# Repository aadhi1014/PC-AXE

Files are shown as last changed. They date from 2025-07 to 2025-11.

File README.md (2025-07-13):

# PC-AXE: PCIe-Based Bitcoin Miner (12x BM1370, 14.4TH/s @ 200W)



**PC-AXE** is a compact, PCIe x4-based, open-hardware Bitcoin miner designed to plug directly into desktop computers. Inspired by [Bitaxe](https://github.com/skot/bitaxe), Bitcrane, and professional mining cards, PC-AXE uses twelve BM1370 ASIC chips and a 6-phase high-efficiency buck converter to deliver up to **14.4TH/s** of hashrate at just **200W** power draw.

**Note:** PC-AXE is a **work in progress**. Hardware files are being finalized, and firmware development is ongoing. Community contributions and testing feedback are welcome.

---

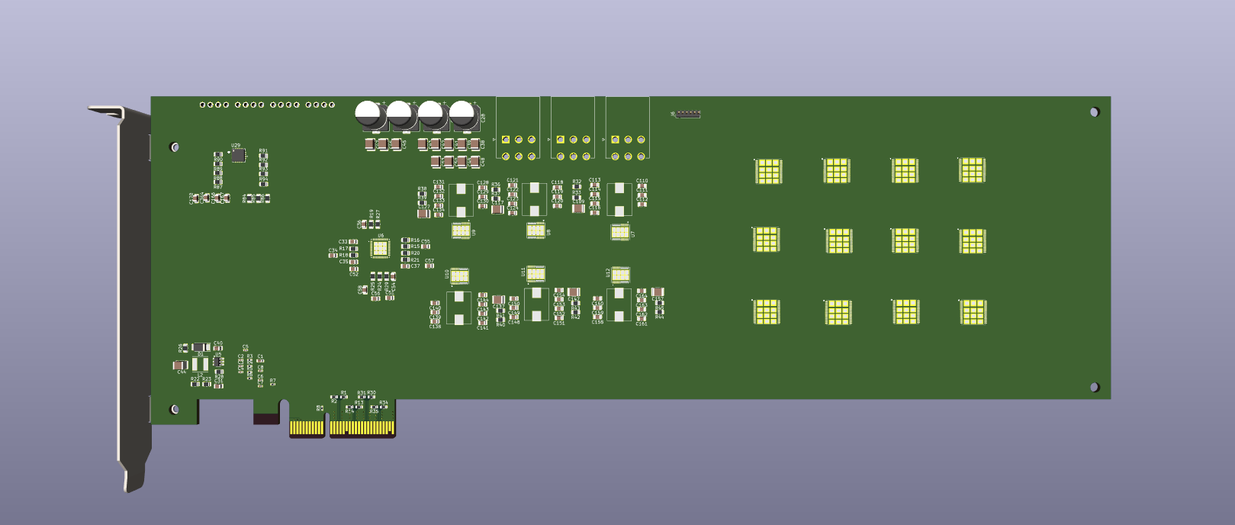
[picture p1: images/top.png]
PC-AXE Top View
  
*Top side of the PC-AXE board*

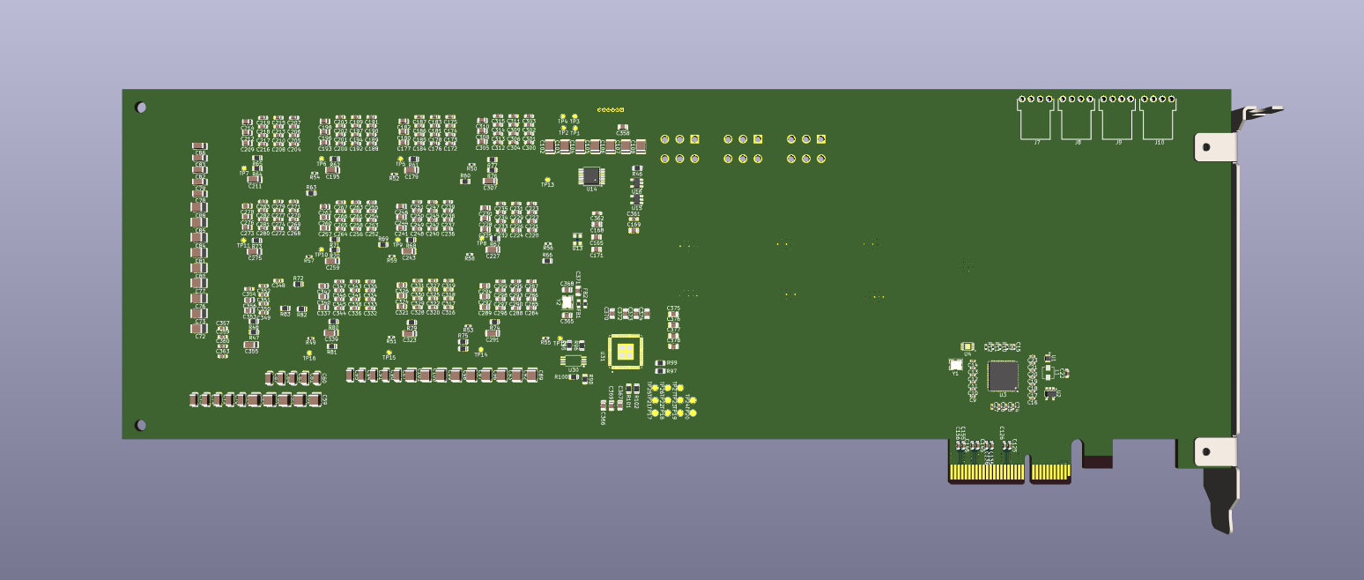
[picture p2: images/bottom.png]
PC-AXE Bottom View
  
*Bottom side of the PC-AXE board*

---

## Features

- **Standard PCIe x4 Form Factor**
  - Easily integrates into modern desktop systems
  - Powered via PCIe slot with external power input

- **12 × BM1370 ASIC Chips**
  - Same chips used in Antminer S21
  - Estimated hashrate of ~1.2TH/s per chip

- **6-Phase 180A Buck Converter**
  - High-efficiency power delivery at 1.1V
  - Total power consumption approximately 200W

- **Fully Open-Source Design**
  - Includes KiCad schematics, layout, and source files
  - Planned firmware compatibility with Bitaxe ecosystem

- **UART Debug Interface**
  - Communicates via USB-to-UART bridge (e.g. FT4232H)
  - Supports daisy-chained UART control for ASICs

- **Design Inspiration**
  - Derived from Bitaxe (compact solo miner)
  - Influenced by Bitcrane

---

## Getting Started

### Build Instructions

1. Open the project in KiCad 7 or newer
2. Review the schematic and PCB layout
3. Export Gerber files and order the PCB from your preferred manufacturer
4. Assemble the board using the BOM (to be published)
5. Flash control firmware (currently in development)

### UART Connection

Connect an FTDI FT4232H or equivalent USB-to-UART adapter to the debug header. A single UART channel can control all 12 ASICs.

---

## Important License Notice  
This project was relicensed under the **TAPR Open Hardware License – Non-Commercial (OHL-NC)** on **July 11, 2025**.  
All clones and forks made **after this date** are subject to **non-commercial use only**.  

**Commercial use, manufacturing, or distribution of this work is strictly prohibited without explicit written permission from the copyright holder.**  

If you cloned this repository *before July 11, 2025*, please contact the author for updated licensing terms.

---

## License

This hardware design is licensed under the TAPR Open Hardware License – Non-Commercial (OHL-NC).  
You are free to use, modify, and distribute for **non-commercial purposes**.  

**Commercial use requires explicit written permission from the copyright holder.**  
See the [LICENSE](LICENSE) file for details.

---

## Acknowledgments

This project draws inspiration and technical insight from several open-source mining hardware efforts:

- [Bitaxe](https://github.com/skot/bitaxe) – foundational open hardware Bitcoin miner  
- [NerdAxe](https://github.com/BitMaker-hub/NerdAxe) – compact ESP32-based BM1370 miner 
- [NerdOCTAXE-Gamma](https://github.com/5toliv/NerdOCTAXE-Gamma) – 8‑ASIC miner derived from NerdQaxe 
- [NerdEKO‑Gamma](https://github.com/phil31/NerdEKO-Gamma) – ESP32-based miner reference design   
- [Bitcrane](https://bitcointalk.org/index.php?topic=951507.0) – USB antminer control board  design

We thank these creators for their contributions to the open-source mining community.
---

## Contact / Collaboration

If you are a developer, hardware enthusiast, or miner interested in contributing to this open hardware project, feel free to open issues or pull requests. Community collaboration is welcome.

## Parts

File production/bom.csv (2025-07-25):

Designator | Footprint | Quantity | Value | LCSC Part #
C1 | 0603 | 1 | 10uF
C10, C11, C12, C13, C14, C16, C17, C18, C19, C23, C24, C27, C3, C4, C5, C6, C7, C8, C9 | 0402 | 19 | 100nF
C100, C101, C102, C103, C104, C105, C106, C107, C108, C59, C62, C65, C66, C69, C72, C73, C76, C77, C80, C81, C84, C85, C88, C89, C92, C93, C96, C97, C98, C99 | 1210 | 30 | 330µF/4V
C109, C117, C127, C137, C147, C157, C38, C39, C41, C42, C43, C44, C45, C46, C47, C48, C49, C50, C53 | 1210 | 19 | 22µ/25V
C110, C118, C128, C138, C148, C158, C169, C171, C180, C196, C212, C228, C244, C260, C276, C292, C308, C324, C340, C356, C52, C54 | 0805 | 22 | 1µF/25V
C111, C116, C119, C124, C129, C134, C139, C144, C149, C154, C159, C164, C36, C37, C58 | 0805 | 15 | 1nF
C112, C113, C115, C120, C121, C123, C130, C131, C133, C140, C141, C143, C150, C151, C153, C160, C161, C163, C165, C166, C167, C168, C170, C182, C198, C214, C230, C246, C262, C278, C294, C310, C326, C342, C358 | 0805 | 35 | 100nF
C114, C122, C132, C142, C152, C162 | 0805 | 6 | 2.2µF/16V
C125, C126, C135, C136, C145, C146, C155, C156 | 0603 | 8 | 100n
C15, C2 | 0402 | 2 | 10uF
C172, C173, C174, C175, C176, C178, C181, C183, C184, C185, C186, C187, C188, C189, C190, C191, C192, C194, C197, C199, C200, C201, C202, C203, C204, C205, C206, C207, C208, C210, C213, C215, C216, C217, C218, C219, C220, C221, C222, C223, C224, C226, C229, C231, C232, C233, C234, C235, C236, C237, C238, C239, C240, C242, C245, C247, C248, C249, C250, C251, C252, C253, C254, C255, C256, C258, C261, C263, C264, C265, C266, C267, C268, C269, C270, C271, C272, C274, C277, C279, C280, C281, C282, C283, C284, C285, C286, C287, C288, C290, C293, C295, C296, C297, C298, C299, C300, C301, C302, C303, C304, C306, C309, C311, C312, C313, C314, C315, C316, C317, C318, C319, C320, C322, C325, C327, C328, C329, C330, C331, C332, C333, C334, C335, C336, C338, C341, C343, C344, C345, C346, C347, C348, C349, C350, C351, C352, C354, C357, C359, C360, C361, C362, C363 | 0603 | 144 | 1µF/6.3V
C177, C193, C209, C225, C241, C257, C273, C289, C305, C31, C321, C337, C353 | 0805 | 13 | 10µF/25V
C179, C195, C211, C227, C243, C259, C275, C291, C307, C323, C339, C355, C60, C61, C63, C64, C67, C68, C70, C71, C74, C75, C78, C79, C82, C83, C86, C87, C90, C91, C94, C95 | 1206 | 32 | 100µ/6.3V
C20 | 0402 | 1 | 10pF
C21 | 0402 | 1 | 1uF
C22 | 0603 | 1 | 22uF
C25, C26 | 0402 | 2 | 18pF
C28, C29, C30, C32 | CP_Elec_8x10 | 4 | 470µ/25V
C33, C35 | 0805 | 2 | 22pF
C34 | 0805 | 1 | 100pF
C364, C369, C371, C372, C373, C374, C375, C376, C377, C378 | 0805 | 10 | 0.1uF | C28233
C365, C368 | 0805 | 2 | 27pf | C107113
C366, C367 | 0805 | 2 | 4.7uF | C1746
C370 | 0805 | 1 | 3.3uF | C159781
C40 | 0805 | 1 | 10nF
C51 | 0805 | 1 | 4.7µF/16V
C55 | 0805 | 1 | 330nF
C56 | 0805 | 1 | 12pF
C57 | 0805 | 1 | 2.2nF
D1 | D_SOD-128 | 1 | PMEG4030EP,115
FB1, FB2 | 0603 | 2 | FerriteBead_Small | C19330
J1 | PCIexpress_bracket_full | 1 | PCIexpress_bracket
J10, J7, J8, J9 | CONN-TH_4P-P2.54_HCTL_HC-2510-4AW | 4 | 61900411021 | C2982043
J2 | PCIexpress_x4 | 1 | PCIexpress_x4
J3, J4, J5 | MOLEX_353180620 | 3 | 353180620
L1 | L_Vishay_IHLP-1212 | 1 | 1uH
L2 | L_Taiyo-Yuden_NR-50xx | 1 | 4.7µH
L3, L4, L5, L6, L7, L8 | IFLR-4031GC-01-8x10 | 6 | 220nH
R1, R13, R14, R2, R30, R31, R34, R35 | 0603 | 8 | 49.9
R10 | 0402 | 1 | 6.04K
R100, R91, R92, R93, R94, R95, R98 | 0805 | 7 | 10k | C17414
R101 | 0805 | 1 | 12k | C17444
R102 | 0805 | 1 | 1k | C17513
R11 | 0402 | 1 | 15K
R12, R5, R6, R8 | 0402 | 4 | 10K
R15, R23 | 0805 | 2 | 16.5K
R16 | 0805 | 1 | 24.3K
R17, R18 | 0805 | 2 | 51 0.5%
R19 | 0805 | 1 | 121K
R20, R21, R46, R47, R48 | 0805 | 5 | 10K
R22 | 0805 | 1 | 86.6K
R24 | 0805 | 1 | 2.55K
R25 | 0805 | 1 | 8.06K
R26 | 0805 | 1 | 49.9K
R27 | 0805 | 1 | 100K
R28, R29 | 0805 | 2 | 2.2R
R3 | 0402 | 1 | 75K
R32, R33, R36, R37, R38, R39, R40, R41, R42, R43, R44, R45 | 0805 | 12 | 1R
R4 | 0402 | 1 | 100K
R49, R50, R51, R52, R53, R54, R55, R56, R57, R58, R59 | 0402 | 11 | 33R
R60, R62, R64, R66, R68, R70, R72, R74, R76, R78, R80, R82 | 0805 | 12 | 1K
R61, R63, R65, R67, R69, R71, R73, R75, R77, R79, R81, R83 | 0805 | 12 | 2K
R7 | 0402 | 1 | DNP
R84, R97, R99 | 0805 | 3 | 4.7k | C17673
R85 | 0805 | 1 | 33k | C17633
R86 | 0805 | 1 | 22k | C17560
R87, R88, R89, R90 | 0805 | 4 | 36k | C114527
R9 | 0402 | 1 | 4.7K
R96 | 0805 | 1 | 2.2k | C17520
TP1, TP10, TP11, TP12, TP13, TP14, TP15, TP16, TP2, TP3, TP4, TP5, TP6, TP7, TP8, TP9 | TestPoint_Pad_D1.0mm | 16 | TestPoint
U1 | SOT-563 | 1 | TLV62568ADRLR
U10, U11, U12, U7, U8, U9 | IC_CSD95490Q5MC | 6 | CSD95472Q5MC
U13 | Oscillator_SMD_EuroQuartz_XO32-4Pin_3.2x2.5mm | 1 | 25MHz
U14 | TSSOP-14-1EP_4.4x5mm_P0.65mm | 1 | TXU0304PW
U15 | SOT-23-5 | 1 | MCP1824T-0802E
U16 | SOT-23-5 | 1 | MCP1824T-1202E
U17, U18, U19, U20, U21, U22, U23, U24, U25, U26, U27, U28 | BM1370 | 12 | BM1370_mode1
U2 | SOT-23-5 | 1 | AP2204K-1.8
U29 | QFN16_4x4MC_MCH | 1 | EMC2305
U3 | QFN-68-1EP_8x8mm_P0.4mm_EP5.2x5.2mm | 1 | VL805
U30 | TSSOP-8_L4.4-W3.0-P0.65-LS6.4-BL | 1 | M93C46-WDW6TP | C616741
U31 | QFN50P900X900X105-65N | 1 | FT4232HQ | C2651882
U4 | DFN-8-1EP_3x2mm_P0.5mm_EP1.36x1.46mm | 1 | W25Q32JVZP
U5 | SOT-23-6 | 1 | AP3211
U6 | IC_TPS53667RTAR | 1 | TPS53667RTAR
Y1 | Crystal_SMD_3225-4Pin_3.2x2.5mm | 1 | 25Mhz
Y2 | Crystal_SMD_3225-4Pin_3.2x2.5mm | 1 | 12MHz | C251626

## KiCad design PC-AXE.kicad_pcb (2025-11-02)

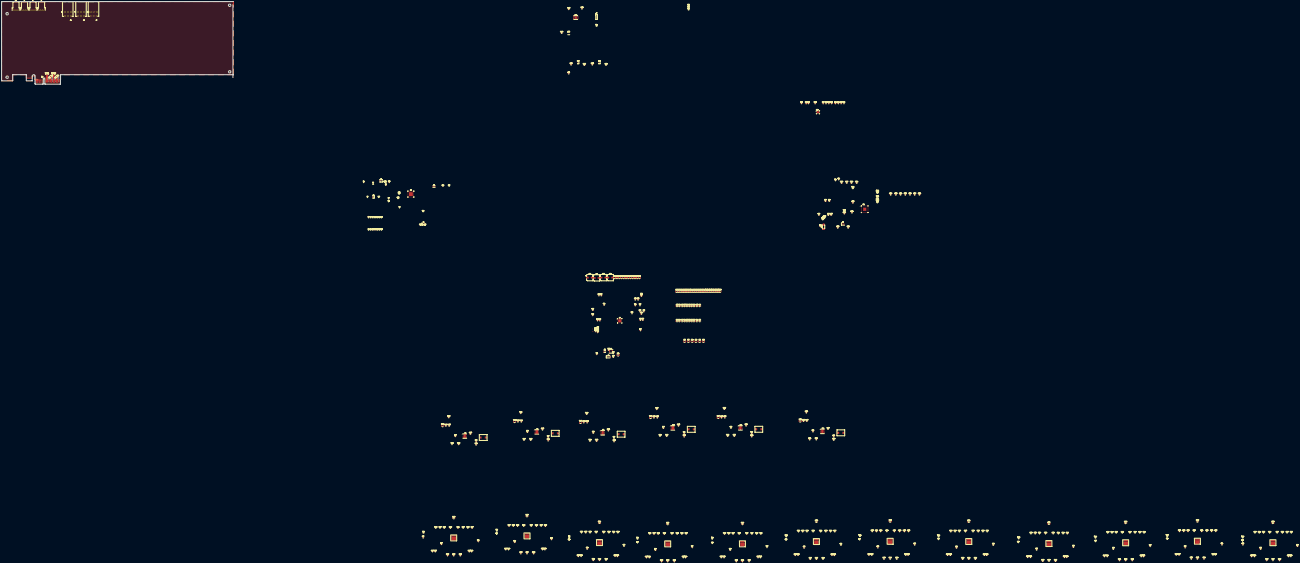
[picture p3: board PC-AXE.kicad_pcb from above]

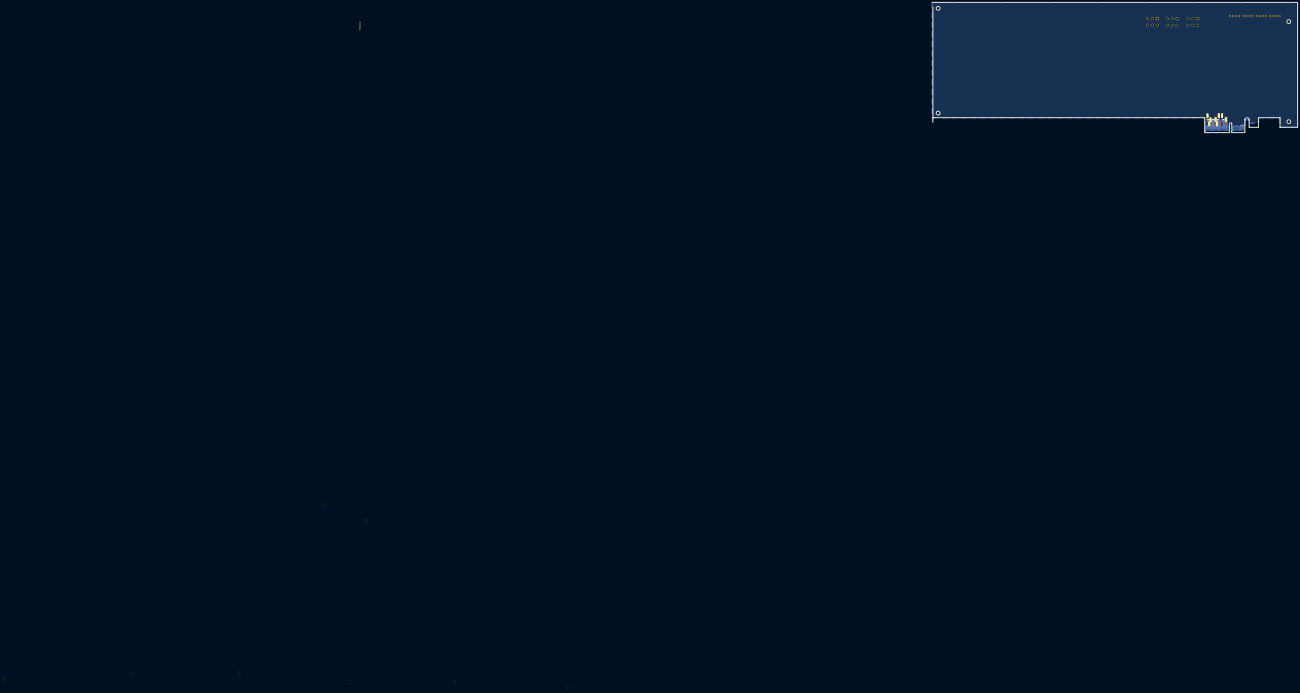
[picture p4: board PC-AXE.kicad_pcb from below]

Board: 6 copper layers, 312.0 x 111.2 mm, 563 parts (8 on the bottom side), 298 nets.

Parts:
C1: 10uF; C_0603_1608Metric
C2, C15: 10uF; C_0402_1005Metric
C3, C4, C5, C6, C7, C8, C9, C10, C11, C12, C13, C14, C16, C17, C18, C19, C23, C24, C27: 100nF; C_0402_1005Metric
C20: 10pF; C_0402_1005Metric
C21: 1uF; C_0402_1005Metric
C22: 22uF; C_0603_1608Metric
C25, C26: 18pF; C_0402_1005Metric
C28, C29, C30, C35: 470µ/25V; CP_Elec_8x10
C31, C177, C193, C209, C225, C241, C257, C273, C289, C305, C321, C337, C353: 10µF/25V; C_0805_2012Metric
C32, C34: 22pF; C_0805_2012Metric
C33: 100pF; C_0805_2012Metric
C36, C37, C58, C111, C116, C119, C124, C129, C134, C139, C144, C149, C154, C159, C164: 1nF; C_0805_2012Metric
C38, C39, C41, C42, C43, C44, C45, C46, C47, C48, C49, C52, C54, C109, C117, C127, C137, C147, C157: 22µ/25V; C_1210_3225Metric
C40: 10nF; C_0805_2012Metric
C50: 4.7µF/16V; C_0805_2012Metric
C51, C53, C110, C118, C128, C138, C148, C158, C169, C171, C180, C196, C212, C228, C244, C260, C276, C292, C308, C324, C340, C356: 1µF/25V; C_0805_2012Metric
C55: 330nF; C_0805_2012Metric
C56: 12pF; C_0805_2012Metric
C57: 2.2nF; C_0805_2012Metric
C59, C62, C65, C66, C69, C72, C73, C76, C77, C80, C81, C84, C85, C88, C89, C92, C93, C96, C97, C98, C99, C100, C101, C102, C103, C104, C105, C106, C107, C108: 330µF/4V; C_1210_3225Metric
C60, C61, C63, C64, C67, C68, C70, C71, C74, C75, C78, C79, C82, C83, C86, C87, C90, C91, C94, C95, C179, C195, C211, C227, C243, C259, C275, C291, C307, C323, C339, C355: 100µ/6.3V; C_1206_3216Metric
C112, C113, C115, C120, C121, C123, C130, C131, C133, C140, C141, C143, C150, C151, C153, C160, C161, C163, C165, C166, C167, C168, C170, C182, C198, C214, C230, C246, C262, C278, C294, C310, C326, C342, C358: 100nF; C_0805_2012Metric
C114, C122, C132, C142, C152, C162: 2.2µF/16V; C_0805_2012Metric
C125, C126, C135, C136, C145, C146, C155, C156: 100n; C_0603_1608Metric
C172, C173, C174, C175, C176, C178, C181, C183, C184, C185, C186, C187, C188, C189, C190, C191, C192, C194, C197, C199, C200, C201, C202, C203, C204, C205, C206, C207, C208, C210, C213, C215, C216, C217, C218, C219, C220, C221, C222, C223, C224, C226, C229, C231, C232, C233, C234, C235, C236, C237, C238, C239, C240, C242, C245, C247, C248, C249, C250, C251, C252, C253, C254, C255, C256, C258, C261, C263, C264, C265, C266, C267, C268, C269, C270, C271, C272, C274, C277, C279, C280, C281, C282, C283, C284, C285, C286, C287, C288, C290, C293, C295, C296, C297, C298, C299, C300, C301, C302, C303, C304, C306, C309, C311, C312, C313, C314, C315, C316, C317, C318, C319, C320, C322, C325, C327, C328, C329, C330, C331, C332, C333, C334, C335, C336, C338, C341, C343, C344, C345, C346, C347, C348, C349, C350, C351, C352, C354, C357, C359, C360, C361, C362, C363: 1µF/6.3V; C_0603_1608Metric_Pad1.08x0.95mm_HandSolder
C364, C369, C371, C372, C373, C374, C375, C376, C377, C378: 0.1uF; C_0805_2012Metric
C365, C368: 27pf; C_0805_2012Metric
C366, C367: 4.7uF; C_0805_2012Metric
C370: 3.3uF; C_0805_2012Metric
D1: PMEG4030EP,115; D_SOD-128
FB1, FB2: FerriteBead_Small; R_0603_1608Metric
J1: PCIexpress_bracket; PCIexpress_bracket_full
J2: PCIexpress_x4
J3, J4, J5: 353180620; MOLEX_353180620
J6: Conn_01x06; PinHeader_1x06_P1.27mm_Vertical
J7, J8, J9, J10: 61900411021; CONN-TH_4P-P2.54_HCTL_HC-2510-4AW
L1: 1uH; L_Vishay_IHLP-1212
L2: 4.7µH; L_Taiyo-Yuden_NR-50xx
L3, L4, L5, L6, L7, L8: 220nH; IFLR-4031GC-01-8x10
NT1, NT2: NetTie_2; NetTie-2_SMD_Pad0.5mm
R1, R2, R13, R14, R30, R31, R34, R35: 49.9; R_0603_1608Metric
R3: 75K; R_0402_1005Metric
R4: 100K; R_0402_1005Metric
R5, R6, R8, R12: 10K; R_0402_1005Metric
R7: DNP; R_0402_1005Metric
R9: 4.7K; R_0402_1005Metric
R10: 6.04K; R_0402_1005Metric
R11: 15K; R_0402_1005Metric
R15, R23: 16.5K; R_0805_2012Metric
R16: 24.3K; R_0805_2012Metric
R17, R18: 51 0.5%; R_0805_2012Metric
R19: 121K; R_0805_2012Metric
R20, R21, R46, R47, R48: 10K; R_0805_2012Metric
R22: 86.6K; R_0805_2012Metric
R24: 2.55K; R_0805_2012Metric
R25: 8.06K; R_0805_2012Metric
R26: 33.2K; R_0805_2012Metric
R27: 100K; R_0805_2012Metric
R28, R29: 2.2R; R_0805_2012Metric
R32, R33, R36, R37, R38, R39, R40, R41, R42, R43, R44, R45: 1R; R_0805_2012Metric
R49, R50, R51, R52, R53, R54, R55, R56, R57, R58, R59: 33R; R_0402_1005Metric_Pad0.72x0.64mm_HandSolder
R60, R62, R64, R66, R68, R70, R72, R74, R76, R78, R80, R82: 1K; R_0805_2012Metric
R61, R63, R65, R67, R69, R71, R73, R75, R77, R79, R81, R83: 2K; R_0805_2012Metric
R84, R97, R99: 4.7k; R_0805_2012Metric
R85: 33k; R_0805_2012Metric
R86: 22k; R_0805_2012Metric
R87, R88, R89, R90: 36k; R_0805_2012Metric
R91, R92, R93, R94, R95, R98, R100: 10k; R_0805_2012Metric
R96: 2.2k; R_0805_2012Metric
R101: 12k; R_0805_2012Metric
R102: 1k; R_0805_2012Metric
TP1, TP2, TP3, TP4, TP5, TP6, TP7, TP8, TP9, TP10, TP11, TP12, TP13, TP14, TP15, TP16: TestPoint; TestPoint_Pad_D1.0mm
TP17, TP18, TP19, TP20, TP21, TP22, TP23, TP24, TP25, TP26, TP27: TestPoint; TestPoint_Pad_D1.5mm
U1: TLV62568ADRLR; SOT-563
U2: AP2204K-1.8; SOT-23-5
U3: VL805; QFN-68-1EP_8x8mm_P0.4mm_EP5.2x5.2mm
U4: W25Q32JVZP; DFN-8-1EP_3x2mm_P0.5mm_EP1.36x1.46mm
U5: AP3211; SOT-23-6
U6: TPS53667RTAR; IC_TPS53667RTAR
U7, U8, U9, U10, U11, U12: CSD95472Q5MC; IC_CSD95490Q5MC
U13: 25MHz; Oscillator_SMD_EuroQuartz_XO32-4Pin_3.2x2.5mm
U14: TXU0304PW; TSSOP-14-1EP_4.4x5mm_P0.65mm
U15: MCP1824T-0802E; SOT-23-5
U16: MCP1824T-1202E; SOT-23-5
U17, U18, U19, U20, U21, U22, U23, U24, U25, U26, U27, U28: BM1370_mode1; BM1370
U29: EMC2305; QFN16_4x4MC_MCH
U30: M93C46-WDW6TP; TSSOP-8_L4.4-W3.0-P0.65-LS6.4-BL
U31: FT4232HQ; QFN50P900X900X105-65N
Y1: 25Mhz; Crystal_SMD_3225-4Pin_3.2x2.5mm
Y2: 12MHz; Crystal_SMD_3225-4Pin_3.2x2.5mm

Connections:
+0V8: C169.1, C173.2, C185.2, C189.2, C201.2, C205.2, C217.2, C221.2, C233.2, C237.2, C249.2, C253.2, C265.2, C269.2, C281.2, C285.2, C297.2, C301.2, C313.2, C317.2, C329.2, C333.2, C345.2, C349.2, C361.2, TP3.1, U15.5 (VOUT), U17.14 (VDDIO_08_0), U17.17 (VDDIO_08_1), U18.14 (VDDIO_08_0), U18.17 (VDDIO_08_1), U19.14 (VDDIO_08_0), U19.17 (VDDIO_08_1), U20.14 (VDDIO_08_0), U20.17 (VDDIO_08_1), U21.14 (VDDIO_08_0), U21.17 (VDDIO_08_1), U22.14 (VDDIO_08_0), U22.17 (VDDIO_08_1), U23.14 (VDDIO_08_0), U23.17 (VDDIO_08_1), U24.14 (VDDIO_08_0), U24.17 (VDDIO_08_1), U25.14 (VDDIO_08_0), U25.17 (VDDIO_08_1), U26.14 (VDDIO_08_0), U26.17 (VDDIO_08_1), U27.14 (VDDIO_08_0), U27.17 (VDDIO_08_1), U28.14 (VDDIO_08_0), U28.17 (VDDIO_08_1)
+1V1: C3.2, C5.2, C7.2, C9.2, C11.2, C13.2, C16.2, C18.2, C20.1, C22.1, L1.2, R3.1, U3.3 (VCCA10SSRX34), U3.9 (VDD), U3.12 (VCCA10SSRX34), U3.29 (VDD), U3.45 (VDD), U3.54 (VCCA10SSRX12), U3.60 (VDD), U3.63 (VCCA10SSRX12)
+1V2: C165.1, C168.1, C171.1, C172.1, C186.1, C188.1, C202.1, C204.1, C218.1, C220.1, C234.1, C236.1, C250.1, C252.1, C266.1, C268.1, C282.1, C284.1, C298.1, C300.1, C314.1, C316.1, C330.1, C332.1, C346.1, C348.1, C362.1, R48.2, TP2.1, U13.1 (Standby), U13.4 (VDD), U14.14 (VCCB), U16.5 (VOUT), U17.15 (VDDIO_12_0), U17.16 (VDDIO_12_1), U18.15 (VDDIO_12_0), U18.16 (VDDIO_12_1), U19.15 (VDDIO_12_0), U19.16 (VDDIO_12_1), U20.15 (VDDIO_12_0), U20.16 (VDDIO_12_1), U21.15 (VDDIO_12_0), U21.16 (VDDIO_12_1), U22.15 (VDDIO_12_0), U22.16 (VDDIO_12_1), U23.15 (VDDIO_12_0), U23.16 (VDDIO_12_1), U24.15 (VDDIO_12_0), U24.16 (VDDIO_12_1), U25.15 (VDDIO_12_0), U25.16 (VDDIO_12_1), U26.15 (VDDIO_12_0), U26.16 (VDDIO_12_1), U27.15 (VDDIO_12_0), U27.16 (VDDIO_12_1), U28.15 (VDDIO_12_0), U28.16 (VDDIO_12_1)
+1V8: C15.1, C370.1, C372.1, C373.1, C374.1, TP21.1, U2.5 (VOUT), U31.12 (VCORE), U31.37 (VCORE), U31.49 (VREGOUT), U31.64 (VCORE)
+3V3: C1.2, C2.1, C4.2, C6.2, C8.2, C10.2, C12.2, C14.2, C17.2, C19.2, C27.2, C166.1, C167.1, C170.1, C364.1, C375.1, C376.1, C377.1, C378.1, FB1.1, FB2.1, J2.A9 (+3.3V), J2.A10 (+3.3V), J2.B8 (+3.3V), R5.2, R6.2, R7.2, R8.2, R11.2, R12.1, R21.1, R84.2, R85.2, R86.2, R87.1, R88.1, R89.1, R90.1, R95.2, R97.2, R98.2, R99.2, R100.2, R102.1, U1.3 (VIN), U1.5 (EN), U2.1 (VIN), U2.3 (EN), U3.6 (VCCA33SS34), U3.15 (VCCA33SS34), U3.23 (VCCA33PEX), U3.32 (VSUS33), U3.46 (VSUS33), U3.49 (VCCA33SSM), U3.57 (VCCA33SS12), U3.66 (VCCA33SS12), U4.7 (IO3), U4.8 (VCC), U14.1 (VCCA), U14.8 (OE), U15.1 (VIN), U16.1 (VIN), U29.3 (VDD), U30.6 (ORG), U30.8 (VCC), U31.20 (VCCIO), U31.31 (VCCIO), U31.42 (VCCIO), U31.50 (VREGIN), U31.56 (VCCIO)
+5V_STDBY: C44.1, L2.2, R22.1, R29.1, R32.1, R36.1, R38.1, R40.1, R42.1, R44.1, R91.2, R92.2, R93.2, R94.2
+12V: C28.1, C29.1, C30.1, C31.1, C35.1, C38.1, C39.1, C41.1, C42.1, C43.1, C45.1, C46.1, C47.1, C48.1, C49.1, C52.1, C54.1, C109.1, C110.1, C112.1, C117.1, C118.1, C120.1, C127.1, C128.1, C130.1, C137.1, C138.1, C140.1, C147.1, C148.1, C150.1, C157.1, C158.1, C160.1, J2.A2 (+12V), J2.A3 (+12V), J2.B1 (+12V), J2.B2 (+12V), J2.B3 (+12V), J3.4, J3.5, J3.6, J4.4, J4.5, J4.6, J5.4, J5.5, J5.6, J7.2, J8.2, J9.2, J10.2, R28.1, U5.4 (EN), U5.5 (IN), U7.7 (VIN), U8.7 (VIN), U9.7 (VIN), U10.7 (VIN), U11.7 (VIN), U12.7 (VIN)
+VREF: C55.1, C56.2, C58.2, C113.1, C121.1, C131.1, C141.1, C151.1, C161.1, R15.2, R24.2, U6.13 (VREF), U7.2 (REFIN), U8.2 (REFIN), U9.2 (REFIN), U10.2 (REFIN), U11.2 (REFIN), U12.2 (REFIN)
/BM1370_chain/BM1370-1/BI: R47.2, U17.9 (BI)
/BM1370_chain/BM1370-1/BO: U17.22 (BO), U18.9 (BI)
/BM1370_chain/BM1370-1/CLKI: TP5.1, U13.3 (Out), U17.8 (CLKI)
/BM1370_chain/BM1370-1/CLKO: R52.1, U17.23 (CLKO)
/BM1370_chain/BM1370-1/CO: U17.25 (CO), U18.6 (CI)
/BM1370_chain/BM1370-1/NRSTO: R61.2, U17.26 (NRSTO), U18.5 (NRSTI)
/BM1370_chain/BM1370-1/RI: U17.24 (RI), U18.7 (RO)
/BM1370_chain/BM1370-2/BO: U18.22 (BO), U19.9 (BI)
/BM1370_chain/BM1370-2/CLKI: R52.2, TP6.1, U18.8 (CLKI)
/BM1370_chain/BM1370-2/CLKO: R54.1, U18.23 (CLKO)
/BM1370_chain/BM1370-2/CO: U18.25 (CO), U19.6 (CI)
/BM1370_chain/BM1370-2/NRSTO: R63.2, U18.26 (NRSTO), U19.5 (NRSTI)
/BM1370_chain/BM1370-2/RI: U18.24 (RI), U19.7 (RO)
/BM1370_chain/BM1370-3/BO: U19.22 (BO), U20.9 (BI)
/BM1370_chain/BM1370-3/CLKI: R54.2, TP7.1, U19.8 (CLKI)
/BM1370_chain/BM1370-3/CLKO: R56.1, U19.23 (CLKO)
/BM1370_chain/BM1370-3/CO: U19.25 (CO), U20.6 (CI)
/BM1370_chain/BM1370-3/NRSTO: R65.2, U19.26 (NRSTO), U20.5 (NRSTI)
/BM1370_chain/BM1370-3/RI: U19.24 (RI), U20.7 (RO)
/BM1370_chain/BM1370-4/BO: U20.22 (BO), U21.9 (BI)
/BM1370_chain/BM1370-4/CLKI: R56.2, TP8.1, U20.8 (CLKI)
/BM1370_chain/BM1370-4/CLKO: R58.1, U20.23 (CLKO)
/BM1370_chain/BM1370-4/CO: U20.25 (CO), U21.6 (CI)
/BM1370_chain/BM1370-4/NRSTO: R67.2, U20.26 (NRSTO), U21.5 (NRSTI)
/BM1370_chain/BM1370-4/RI: U20.24 (RI), U21.7 (RO)
/BM1370_chain/BM1370-5/BO: U21.22 (BO), U22.9 (BI)
/BM1370_chain/BM1370-5/CLKI: R58.2, TP9.1, U21.8 (CLKI)
/BM1370_chain/BM1370-5/CLKO: R59.1, U21.23 (CLKO)
/BM1370_chain/BM1370-5/CO: U21.25 (CO), U22.6 (CI)
/BM1370_chain/BM1370-5/NRSTO: R69.2, U21.26 (NRSTO), U22.5 (NRSTI)
/BM1370_chain/BM1370-5/RI: U21.24 (RI), U22.7 (RO)
/BM1370_chain/BM1370-6/BO: U22.22 (BO), U23.9 (BI)
/BM1370_chain/BM1370-6/CLKI: R59.2, TP10.1, U22.8 (CLKI)
/BM1370_chain/BM1370-6/CLKO: R57.1, U22.23 (CLKO)
/BM1370_chain/BM1370-6/CO: U22.25 (CO), U23.6 (CI)
/BM1370_chain/BM1370-6/NRSTO: R71.2, U22.26 (NRSTO), U23.5 (NRSTI)
/BM1370_chain/BM1370-6/RI: U22.24 (RI), U23.7 (RO)
/BM1370_chain/BM1370-7/BO: U23.22 (BO), U24.9 (BI)
/BM1370_chain/BM1370-7/CLKI: R57.2, TP11.1, U23.8 (CLKI)
/BM1370_chain/BM1370-7/CLKO: R55.1, U23.23 (CLKO)
/BM1370_chain/BM1370-7/CO: U23.25 (CO), U24.6 (CI)
/BM1370_chain/BM1370-7/NRSTO: R73.2, U23.26 (NRSTO), U24.5 (NRSTI)
/BM1370_chain/BM1370-7/RI: U23.24 (RI), U24.7 (RO)
/BM1370_chain/BM1370-8/BO: U24.22 (BO), U25.9 (BI)
/BM1370_chain/BM1370-8/CLKI: R55.2, TP12.1, U24.8 (CLKI)
/BM1370_chain/BM1370-8/CLKO: R53.1, U24.23 (CLKO)
/BM1370_chain/BM1370-8/CO: U24.25 (CO), U25.6 (CI)
/BM1370_chain/BM1370-8/NRSTO: R75.2, U24.26 (NRSTO), U25.5 (NRSTI)
/BM1370_chain/BM1370-8/RI: U24.24 (RI), U25.7 (RO)
/BM1370_chain/BM1370-9/CLKI: R53.2, TP13.1, U25.8 (CLKI)
/BM1370_chain/BM1370-9/CLKO: R50.1, U25.23 (CLKO)
/BM1370_chain/BM1370-10/BI: U25.22 (BO), U26.9 (BI)
/BM1370_chain/BM1370-10/BO: U26.22 (BO), U27.9 (BI)
/BM1370_chain/BM1370-10/CI: U25.25 (CO), U26.6 (CI)
/BM1370_chain/BM1370-10/CLKI: R50.2, TP14.1, U26.8 (CLKI)
/BM1370_chain/BM1370-10/CLKO: R51.1, U26.23 (CLKO)
/BM1370_chain/BM1370-10/CO: U26.25 (CO), U27.6 (CI)
/BM1370_chain/BM1370-10/NRSTI: R77.2, U25.26 (NRSTO), U26.5 (NRSTI)
/BM1370_chain/BM1370-10/NRSTO: R79.2, U26.26 (NRSTO), U27.5 (NRSTI)
/BM1370_chain/BM1370-10/RI: U26.24 (RI), U27.7 (RO)
/BM1370_chain/BM1370-10/RO: U25.24 (RI), U26.7 (RO)
/BM1370_chain/BM1370-11/BO: U27.22 (BO), U28.9 (BI)
/BM1370_chain/BM1370-11/CLKI: R51.2, TP15.1, U27.8 (CLKI)
/BM1370_chain/BM1370-11/CLKO: R49.1, U27.23 (CLKO)
/BM1370_chain/BM1370-11/CO: U27.25 (CO), U28.6 (CI)
/BM1370_chain/BM1370-11/NRSTO: R81.2, U27.26 (NRSTO), U28.5 (NRSTI)
/BM1370_chain/BM1370-11/RI: U27.24 (RI), U28.7 (RO)
/BM1370_chain/BM1370-12/CLKI: R49.2, TP16.1, U28.8 (CLKI)
/BM1370_chain/BM1370-12/NRSTO: R83.2, U28.26 (NRSTO)
/BM1370_chain/BM1370-12/RI: R48.1, U28.24 (RI)
/BM1370_chain/CI: J6.4, U14.12 (B2Y), U17.6 (CI)
/BM1370_chain/RO: J6.5, U14.10 (B4), U17.7 (RO)
/BM1370_chain/RST_N: J6.3, TP1.1, U14.13 (B1Y), U17.5 (NRSTI)
/DN: U3.59 (USB2D1-), U31.7 (DM)
/DP: U3.58 (USB2D1+), U31.8 (DP)
/FAN/PWM1: J7.4, R91.1, U29.5 (PWM1)
/FAN/PWM2: J8.4, R92.1, U29.7 (PWM2)
/FAN/PWM3: J9.4, R93.1, U29.9 (PWM3)
/FAN/PWM4: J10.4, R94.1, U29.13 (PWM4)
/FAN/TACH1: J7.3, R87.2, U29.6 (TACH1)
/FAN/TACH2: J8.3, R88.2, U29.8 (TACH2)
/FAN/TACH3: J9.3, R89.2, U29.10 (TACH3)
/FAN/TACH4: J10.3, R90.2, U29.14 (TACH4)
/FAN_ALERT: R84.1, TP24.1, U29.12 (~ALERT), U31.23 (ADBUS6)
/LDO_EN: R46.1, U15.3 (EN), U16.3 (EN)
/PCIexpress_connector/_PER0_N: C126.1, J2.A17 (PERn0)
/PCIexpress_connector/_PER0_P: C125.2, J2.A16 (PERp0)
/PCIexpress_connector/_PER1_N: C136.1, J2.A22 (PERn1)
/PCIexpress_connector/_PER1_P: C135.2, J2.A21 (PERp1)
/PCIexpress_connector/_PER2_N: C146.1, J2.A26 (PERn2)
/PCIexpress_connector/_PER2_P: C145.2, J2.A25 (PERp2)
/PCIexpress_connector/_PER3_N: C156.1, J2.A30 (PERn3)
/PCIexpress_connector/_PER3_P: C155.2, J2.A29 (PERp3)
/PER0_N: C23.1, C126.2
/PER0_P: C24.1, C125.1
/PET0_N: J2.B15 (PETn0), R1.1, U3.27 (PE_RXP)
/PET0_P: J2.B14 (PETp0), R2.1, U3.28 (PE_RXN)
/PET1_N: J2.B20 (PETn1), R13.1
/PET1_P: J2.B19 (PETp1), R14.1
/PET2_N: J2.B24 (PETn2), R30.1
/PET2_P: J2.B23 (PETp2), R31.1
/PET3_N: J2.B28 (PETn3), R34.1
/PET3_P: J2.B27 (PETp3), R35.1
/POWER/FCCM: R27.2, U6.39 (~SKIP-NVM), U7.10 (FCCM), U8.10 (FCCM), U9.10 (FCCM), U10.10 (FCCM), U11.10 (FCCM), U12.10 (FCCM)
/POWER/Power_stage1/VDD: L3.2, L4.2, L6.2, L7.2, L8.2
/POWER/TPS_CSP1: U6.3 (CSP1), U9.1 (IOUT)
/POWER/TPS_CSP2: U6.4 (CSP2), U7.1 (IOUT)
/POWER/TPS_CSP3: U6.5 (CSP3), U8.1 (IOUT)
/POWER/TPS_CSP4: U6.6 (CSP4), U10.1 (IOUT)
/POWER/TPS_CSP5: U6.7 (CSP5), U11.1 (IOUT)
/POWER/TPS_CSP6: U6.8 (CSP6), U12.1 (IOUT)
/POWER/TPS_PWM1: U6.38 (PWM1), U9.12 (PWM)
/POWER/TPS_PWM2: U6.37 (PWM2), U7.12 (PWM)
/POWER/TPS_PWM3: U6.36 (PWM3), U8.12 (PWM)
/POWER/TPS_PWM4: U6.35 (PWM4), U10.12 (PWM)
/POWER/TPS_PWM5: U6.34 (PWM5), U11.12 (PWM)
/POWER/TPS_PWM6: U6.33 (PWM6), U12.12 (PWM)
/POWER/TSEN: C36.1, C111.1, C119.1, C129.1, C139.1, C149.1, C159.1, R19.2, U6.40 (TSEN), U7.11 (TAO/FAULT), U8.11 (TAO/FAULT), U9.11 (TAO/FAULT), U10.11 (TAO/FAULT), U11.11 (TAO/FAULT), U12.11 (TAO/FAULT)
/POWER/VSENSE+: NT1.2, R17.1
/POWER/VSENSE-: NT2.2, R18.1
/POWER//RESET: R21.2, U6.21 (~RESET)
/REFCLK+: J2.A13 (REFCLK+), U3.21 (PE_CLKP)
/REFCLK-: J2.A14 (REFCLK-), U3.22 (PE_CLKN)
/RESET_N: TP27.1, U14.2 (A1), U31.28 (BDBUS2)
/RXD: TP26.1, U14.5 (A4Y), U31.27 (BDBUS1)
/SCL: R97.1, TP22.1, U6.24 (PMB_CLK), U29.2 (SMCLK), U31.16 (ADBUS0)
/SDA: R99.1, TP23.1, U6.26 (PMB_DIO), U29.1 (SMDATA), U31.17 (ADBUS1), U31.18 (ADBUS2)
/TXD: TP25.1, U14.3 (A2), U31.26 (BDBUS0)
/USB/PCIe_CLK_REQ: R6.1, U3.30 (~PE_CLKREQ)
/USB/SMI: R7.1, U3.18 (~SMI)
/VR_ENABLE: C37.1, R20.1, U6.23 (ENABLE), U31.19 (ADBUS3)
/VR_READY: U6.18 (VR_RDY), U31.21 (ADBUS4)
/~PERST: J2.A11 (~PERST), U3.19 (~PE_RST)
/~WAKE: J2.B11 (~WAKE), R8.1, U3.20 (~PE_WAKE)
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

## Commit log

2025-07-02 Initial commit: Added KiCad project files
    [BM1370_Chain.kicad_sch, Fan_cntrl.kicad_sch, PC-AXE.kicad_pcb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]
2025-07-25 board stakup updated and schematic is updated
    [BM1370_Chain.kicad_sch, Fan_cntrl.kicad_sch, PC-AXE.kicad_pcb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]
2025-11-02 updated schematic working on layout
    [BM1370_Chain.kicad_sch, Fan_cntrl.kicad_sch, PC-AXE.kicad_pcb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]
2025-12-06 Updated new layout and routing of PCB
    [BM1370_Chain.kicad_sch, PC-AXE_backup_altium.kicad_pcb, USB_to_UART.kicad_sch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]
2025-12-06 Removed backup files from tracking and updated .gitignore
    [PC-AXE_backup_altium.kicad_pcb]

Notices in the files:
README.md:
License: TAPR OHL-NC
